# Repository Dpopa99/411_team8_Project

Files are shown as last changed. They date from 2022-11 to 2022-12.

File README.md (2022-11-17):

* Group Member Names: David Popa | Jade Nguyen | Pushpesh Sharma | Shyamal Singh
* Title: ElectroBoom
* Course: ECE411 Fall 2022
* Date: Oct 13, 2022
* Revision: Version 1.0

# Problem Statement and Concept of Operations
Self defense is a necessity in our everyday lives. Whether you go on late night walks in downtown or spend your time in the rural side of town, you have to be prepared to defend yourself in a attack on your person. The stun gun in its mounted state creates a non-lethal electric shock used to stop an intruder from trespassing in an unauthorized area. The device is connected to an entrance door and upon activation of the device, any unauthorized operation of the door will send an electric shock from the device to the door thus immobilizing the assailant. Although they lack some advantages, such as the capacity to render an adversary helpless or a larger range, they are highly regarded for their ease of use and accessibility. The device is mounted, its size and weight make it portable and versatile. The overall product offers a sense of security and vigilance and should be marketed as such. The final marketing team should strongly consider any number of regulations as well as the variance in stand your ground laws within the U.S and internationally. 

# Market Analysis 
As a mounted device, it can be used by a vast number of customers such as small businesses owners, street food vendors, landlords, storage units owners, RV/Van campers, etc. to protect their belongings and themselves.
Over the development of the product, it can be marketed to bigger businesses, corporate offices, banks, armored vehicles, private security firms, as well as in home security companies. 

The competition can be felt through any of the manufacturers selling pre-installed security devices as well as products that offer multipurpose use such as the Ring Doorbell etc. Our product is in a completely different region as it targets a specific audience: the self-made individuals who are vigilant and don't hesitate to do what's necessary to protect what's theirs. 
	
In comparison to other security devices and their features, our device can be priced within the $40-$50 range. There are several key factors that affect this price and as our design and overall ideas develop, the price may be adjusted accordingly. Factors like the mounting apparatus, 3D printed casing, any user interfaces used, and the cost of internal parts such as the transformer, connectors, and the PCB will eventually determine the final price for our product. 

# Product Requirements
* Must be a rugged design for versatile use and placement.
* Must send a non-lethal electric shock.
* Must be marketed as a plug in device. 
* Must not overheat. (Check transformer behavior in various situations)
* Must be operated via a Door actuated sensor. 
* Should have the ability to be deactivated via remote or physical switch. 
* Should have LED indicators to dictate state of device (Armed or Disarmed)
* May have 3D printed enclosure for all components
* May have Display to show state of device (Active, Triggered, Inactive)

# System Architecture (Currently in Design)
Option 1
Option 2

# Design Specification
* Sensor: Door knob movement actuating motion sensor, metal contact to send electric shock
* Processor: ATMega328P microcontroller with Arduino IDE for processing motion sensor activity to send electric shock via transformer. Firmware used will be the Bootloader.  
* Actuator: High voltage transformer taking input voltage and sending converted voltage at variable frequency chosen shock apparatus. 
* Power: 9V wall adapter feeding a high voltage transformer 

# Breadboard Prototype



 As seen from pictures above, the prototype is about finished and all that is needed to have a fully working prototype is the transformer (parts on their way). Image 1 shows the green LED on while the two door sensors are attached, this indicates that the system is armed and ready to go. In the second image, a red LED is shown, meaning that the door has been triggered and the voltage would be discharged out of the two open prongs that would be if the transformer parts were obtained. The video below shows the working prototype.
 
 Current status 11/02/2022: We are awaiting the arrival of our 3.3V to 2000V transformer, upon arrival, we will assemble, test, and commit this transformer to our circuit. Along with this transformer, we will run tests to ensure that the voltage and current combinations will be safe for human contact, however, it is still reccomended that all testing be done by non-human contact, for the safety of our staff, faculty, and students. 

https://user-images.githubusercontent.com/115689153/199646965-d1418cc2-3406-4b21-8939-66e534c145ff.mov

# License
GNU General Public License v2.0
The GNU GPL is the most widely used free software license and has a strong copyleft requirement. When distributing derived works, the source code of the work must be made available under the same license. There are multiple variants of the GNU GPL, each with different requirements.

See Documentation file in this repository for all sources used for this project

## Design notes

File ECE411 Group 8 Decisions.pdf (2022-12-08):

David Popa
Jade Nguyen
Shyamal Singh
Pushpesh Sharma
ECE 411 Group 8

# Stun Gun Decision Making Strategies

Concept 1: Stun Gun Transformer

- Decision Matrix
| | Flyback Transformer | Forward Transformer (LM5015MHE) | Boost Converter (VXO78012)
Output Voltage Range | 5 | 5 | 2 | 1
Current Range | 5 | 4 | 1 | 2
Size | 2 | 3 | 4 | 2
Price | 3 | 5 | 3 | 4
Operating Temperature | 2 | 5 | 3 | 5
Score | | 76 | 38 | 39
- Analytical Hierarchy Process
| | Flyback Transformer | Forward Transformer (LM5015MH E) | Boost Converter (VXO78012)
Output Voltage Range | 0.45 | 0.12 | 0.29 | 0.59
Current Range | 0.40 | 0.26 | 0.43 | 0.32
Size | 0.09 | 0.53 | 0.26 | 0.21
Price | 0.03 | 0.45 | 0.2 | 0.4
Operating Temperature | 0.03 | 0.31 | 0.38 | 0.31
Score | | 0.23 | 0.34 | 0.43

For the transformer, the Decision Matrix vs the AHP values do not match. The calculations for the AHP were based on stars given to some of the categories that could not be quantified and the weights for those specific categories could be the root cause of the differences we see in the tables. For our needs and requirements for the practicum project, we will be choosing the Flyback transformer.

Concept 2: Position Sensor for Stun Activation

- Decision Matrix
Magnetic Door Sensor (Normally Open Closed NC/NO) | Ultrasonic Sensor (HC-SR04) | Motion Sensor (HC-SR501)
Detection | 3 | 5 | 4 | 3
Price | 3 | 2 | 2 | 5
Operating voltage | 4 | 3 | 5 | 3
Trigger range | 2 | 5 | 4 | 3
Delay time | 4 | 5 | 3 | 1
Score | | 63 | 58 | 46
- Analytical Hierarchy Process
Magnetic Door Sensor (NC/NO) | Ultrasonic Sensor (HC-SR04) | Motion Sensor (HC-SR501)
Detection | 0.36 | 0.42 | 0.33 | 0.25
Price | 0.36 | 0.26 | 0.26 | 0.48
Operating voltage | 0.15 | 0.38 | 0.42 | 0.20
Trigger range | 0.1 | 0.40 | 0.32 | 0.28
Delay time | 0.04 | 0.11 | 0.81 | 0.08
Score | | 0.35 | 0.34 | 0.32

The decision matrix and the AHP both point towards the Magnetic Door Sensor. Again some of the categories were given stars to quantify as the actual values were not comparable between the alternatives. The final decision is also based on the overall structure and marketing aspect of our project. Thus we will be going with the Magnetic Door Sensor. Linked Sheets file for all calculations available upon request.

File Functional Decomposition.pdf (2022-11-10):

David Popa
Jade Nguyen
Shyamal Singh
Pushpesh Sharma
ECE 411 Group 8

# Stun Gun Functional Decomposition

Top- Level (Level 0) Block Diagram

Module | Stun Gun Device
Inputs | ● Input Signal from Magnetic Door Sensor ● Power from 9V Wall Adapter ● Toggle Switch to Activate overall System
Outputs | ● Voltage Booster Output: 2kV (Output current: 0.5~1mA; external parallel capacitor can increase the output current) ● LCD and LED displaying system status ● Buzzer Alarm
Functionality | 3.3 V input from Arduino after input signal received from magnetic door sensor as door knob is operated. Voltage boosted through the module up to ~ 2kV to create arc and shock through the hand on door knob. LCD display showing system status as armed or disarmed or trespassed. Green or red LEDs showing system status. Buzzer alarm when trespass detected.

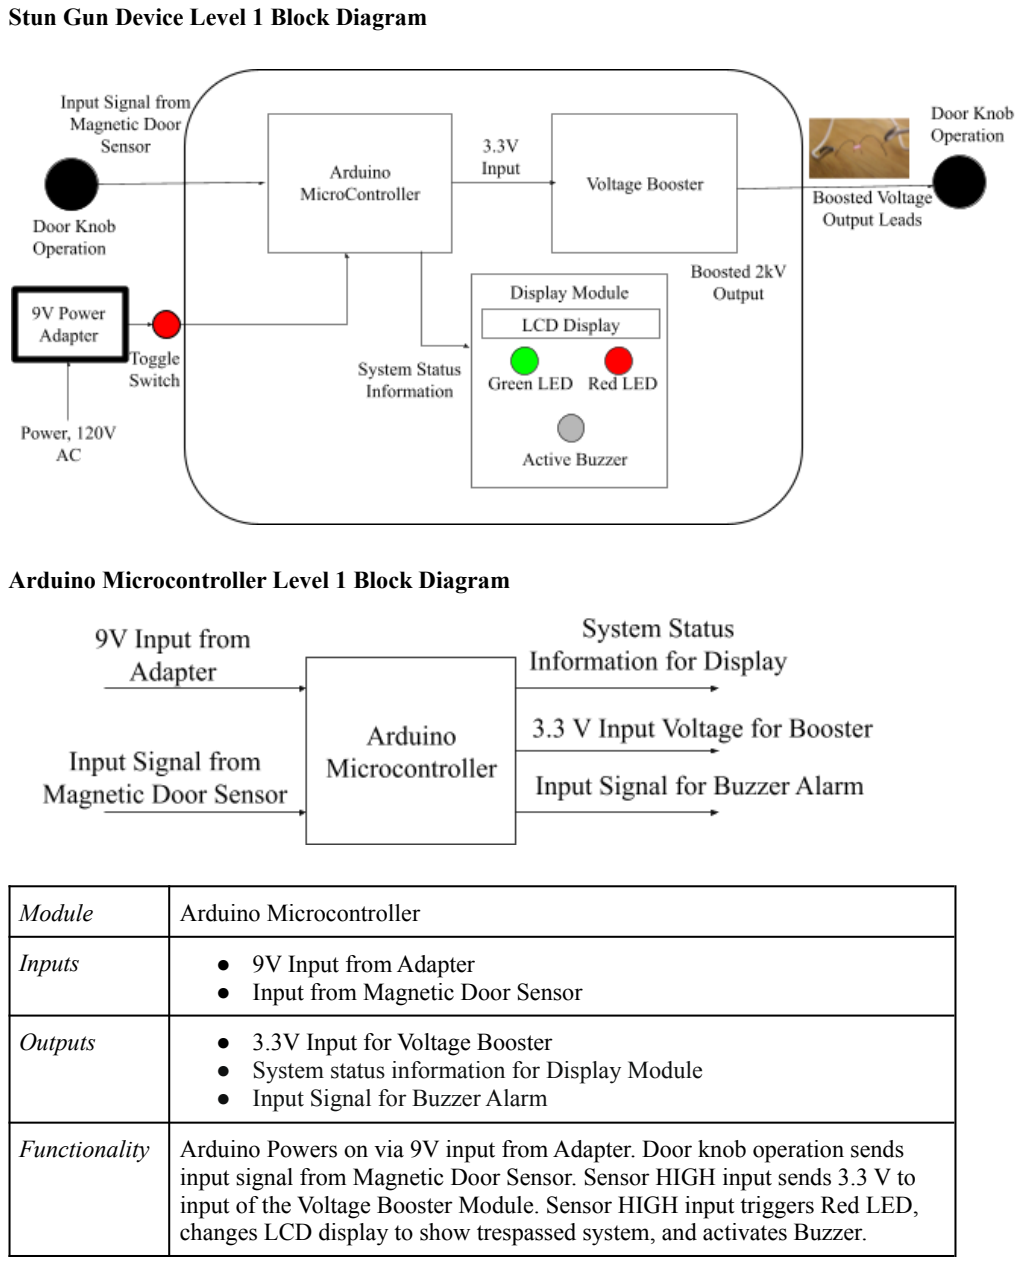
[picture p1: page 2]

Stun Gun Device Level 1 Block Diagram

Arduino Microcontroller Level 1 Block Diagram

Module | Arduino Microcontroller
Inputs | ● 9V Input from Adapter ● Input from Magnetic Door Sensor
Outputs | ● 3.3V Input for Voltage Booster
- System status information for Display Module
- Input Signal for Buzzer Alarm

Functionality Arduino Powers on via 9V input from Adapter. Door knob operation sends input signal from Magnetic Door Sensor. Sensor HIGH input sends 3.3 V to input of the Voltage Booster Module. Sensor HIGH input triggers Red LED, changes LCD display to show trespassed system, and activates Buzzer.

Voltage Booster Level 1 Block Diagram

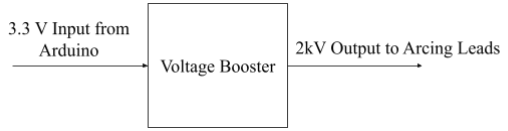
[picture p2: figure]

Module | Voltage Booster
Inputs | ● 3.3V Input from Arduino
Outputs | ● 2000V Output through Arcing Leads connected to door knob.
Functionality | Voltage booster module has active and passive components along with a transformer that boosts the input voltage from 3V-4.2V to 1500V-2000V. The output creates arcing between the two leads and touching the leads sends shock to the user's hand.

Display Module Level 1 Block Diagram

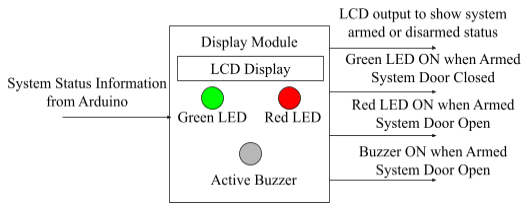
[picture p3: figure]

Module | Display Module
Inputs | ● Input from Arduino
Outputs | ● System status displays on LCD ● LEDs indicates door close/open ● Signal for Buzzer Alarm
Functionality | System status input from the Arduino activates Red LED when sensor input HIGH, which also modifies the LCD display to show the trespassed system and turns on Buzzer.

Power Supply Level 1 Block Diagram

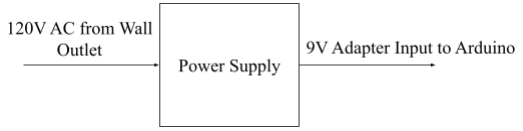
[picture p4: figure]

Module | Power Supply
Inputs | ● 120V AC from wall outlet
Outputs | ● | 9V Adapter Input to Arduino
Functionality | Wall outlet to 9V adapter for arduino. Toggle switch in between to help create
Armed or Disarmed states for the system. No power to the system is disarmed. Once the toggle switch is flipped, system is armed and ready for input signal from Magnetic Door Sensor.

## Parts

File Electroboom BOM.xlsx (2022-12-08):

Bill of Materials
Category | Part Name | Manufacturer | Mfg Part Number | Quantity | Image | Quanity Used | Description | Units Ordered | Cost Each | Cost Total | Distributor | Source
Controller | ELEGOO UNO R3 | ELEGOO | 746591610715 | 1 |  | 4 | ELEGOO UNO R3 Board ATmega328P with USB Cable(Arduino-Compatible) | 4 | $17.99 | $71.96 | Amazon | Elegoo UNO R3 (https://www.amazon.com/ELEGOO-Board-ATmega328P-ATMEGA16U2-Compliant/dp/B01EWOE0UU)
Sensors | Magnetic Door Sensor | Dairzitv | EWWE-87878 | 10 |  | 4 | Surface Mount Wired NC Door Contact Sensor (Pack of 10) | 1 | $1.10 | $10.99 | Amazon | Magnetic Door Sensor (https://a.co/d/hY13WqR)
Actuators | Booster Module | QINIZX | B09BLQQRHL | 2 |  | 4 | Voltage Generator Module Arc Pulse Booster (3V-4.2V boost 2000V) (Pack of 2) | 2 | $5.50 | $21.98 | Amazon | Voltage Booster (https://a.co/d/2gN0GyB)
 | Toggle Switch | AdaFruit | 3218 | 1 |  | 4 | Illuminated Toggle Switch with Cover (Red) Actuation Style: Rocker | 4 | $3.95 | $15.80 | AdaFruit | Toggle Switch (https://www.adafruit.com/product/3218)
Displays | LCD Screen | HiLetgo | 16497 | 2 |  | 4 | LCD Display Module DC 5V 16x2 Character LCM Blue Blacklight (Pack of 2) | 2 | $4.50 | $18.00 | Amazon | LCD Display (https://a.co/d/4aTC4eN)
 | LED indicators | Kingbright | WP154A4SUREQBFZGC | 1 |  | 4 | LED RGB CLEAR T-1 3/4 T/H | 4 | $3.01 | $12.04 | Digikey | RGB LED (https://www.digikey.ca/short/cf37n9db)
Connectors | Header CONN | Molex | 22284028 | 2 |  | 8 | Connector Header Through Hole 2 position 0.100" (2.54mm) | 2 | $0.28 | $0.56 | Digikey | Header (https://www.digikey.com/en/products/detail/molex/0022284028/314032)
 | Arduino Shield Connectors | AdaFruit | 85 | 6 |  | 4 | Shield stacking headers for Arduino (R3 Compatible) | 1 | $0.33 | $1.95 | AdaFruit | Stacking Shield CONN (https://www.adafruit.com/product/85)
 | Arduino LCD Header | Antrader | B07GP3TLH9 | 40 |  | 4 | 2.54mm 16Pin Single Row PBC Female Pin Header Socket Connector Strip | 1 | $0.16 | $6.49 | Amazon | 16 Pin Header (https://a.co/d/b6fevxA)
Passive Compnents | 300 Ohm Resistor | YAGEO | RC0805JR-07330RL | 1 |  | 8 | RES 330 OHM 5% 1/8W 0805 | 8 | $0.10 | $0.80 | Digikey | 300 Ohm Resistor (https://www.digikey.com/short/ntbppq7n)
 | 10k Ohm Resistor | YAGEO | RC0805FR-0710KL | 1 |  | 4 | RES 10K OHM 1% 1/8W 0805 | 4 | $0.10 | $0.40 | Digikey | 10k Ohm Resistor (https://www.digikey.com/short/373h2zrv)
 | Potentiometer | Bourns | 3362P-1-103LF | 1 |  | 4 | TRIMMER 10K OHM 0.5W PC PIN TOP | 4 | $1.03 | $4.12 | Digikey | Trimmer (https://www.digikey.com/en/products/detail/bourns-inc./3362P-1-103LF/1088412)
 | SMD Diode | MDD | 1N4148W | 1 |  | 4 | Diode Standard 100 V 150mA Surface Mount SOD-123 | 4 | $0.05 | $0.18 | Digikey | Diode (https://www.digikey.com/en/products/detail/nextgen-components,-inc./1N4148W%2520T4/14825027)
 | Switch | E-Switch | EG1218 | 1 |  | 4 | Slide Switch SPDT Through Hole | 4 | $0.76 | $3.04 | Digikey | Onboard Switch (https://www.digikey.com/en/products/detail/e-switch/EG1218/101726)
 | IR Sensor and Remote | DFRobot | 2152315 | 1 |  | 4 | Infrared Remote & IR Receiver Combo Arduino Compatible | 4 | $7.49 | $29.96 | Jameco | IR sensor and Remote (https://www.jameco.com/z/DFR0107-DFRobot-Infrared-Remote-IR-Receiver-Combo-Arduino-Compatible_2152315.html)
Power | 9V Batteries | Duracell | MN1604B4 | 4 |  | 4 | Duracell Coppertop 9V Battery (Pack of 4) | 1 | $3.05 | $12.19 | Amazon | 9V Batteries (https://a.co/d/fda0Lso)
 | 9V Battery Connector | RFAdapter | B0882VV74L | 6 |  | 4 | 9v Battery Clip with 5.5mm/2.1mm Male DC Plug | 1 | $1.00 | $5.99 | Amazon | 9V Battery Connector (https://a.co/d/hpMY8ct)
 | Power Adapter | Corporate Computer | LJH -186 | 1 |  | 4 | 9VDC 1A Arduino Compatible Power Supply Adapter 110V AC 5.5 x 2.1mm Tip | 4 | $7.49 | $7.49 | Amazon | 9V Battery Adapter (https://a.co/d/gGLW0Xa)
EDA | PCB Fabrication | OshPark | n/a | 4 |  | 4 | Layout to house and control LCD display, LED indicators, and Voltage Booster Module | 1 | $7.14 | $28.55 | OshPark | OshPark (https://oshpark.com/)
Component Housing | 3D Enclosure v1 | EPL | n/a | 1 |  | 4 | 3D Enclosure for Component Housing | 4 | $15.00 | $60.00 | EPL | 3DPrinting (http://psu-epl.github.io/doc/equip/printer/3D-Printers.html)
 | 3D Enclosure v2 | EPL | n/a | 1 |  | 4 | 3D Enclosure for Component Housing | 4 | $20.00 | $80.00 | EPL | 3DPrinting (http://psu-epl.github.io/doc/equip/printer/3D-Printers.html)
 |  |  |  |  |  |  | Total Cost for all Components: |  |  | $392.49
Revisions | Date |  |  |  |  |  | Total Cost Per Device: |  | $96.90
v1: Added Headers for PCB | 2022-10-12 |  |  |  |  |  | Total Cost for all 4 Devices: |  | $387.58
v2: Added 9V Battery Connector | 2022-10-31
v3: Added IR sensor and Remote | 2022-11-15
v4: Added Toggle Switch | 2022-11-17
v5: Added PCB | 2022-11-21
v6: Added 3D enclosure v1 | 2022-12-01
v7: Added 3D enclousre v2 | 2022-12-04

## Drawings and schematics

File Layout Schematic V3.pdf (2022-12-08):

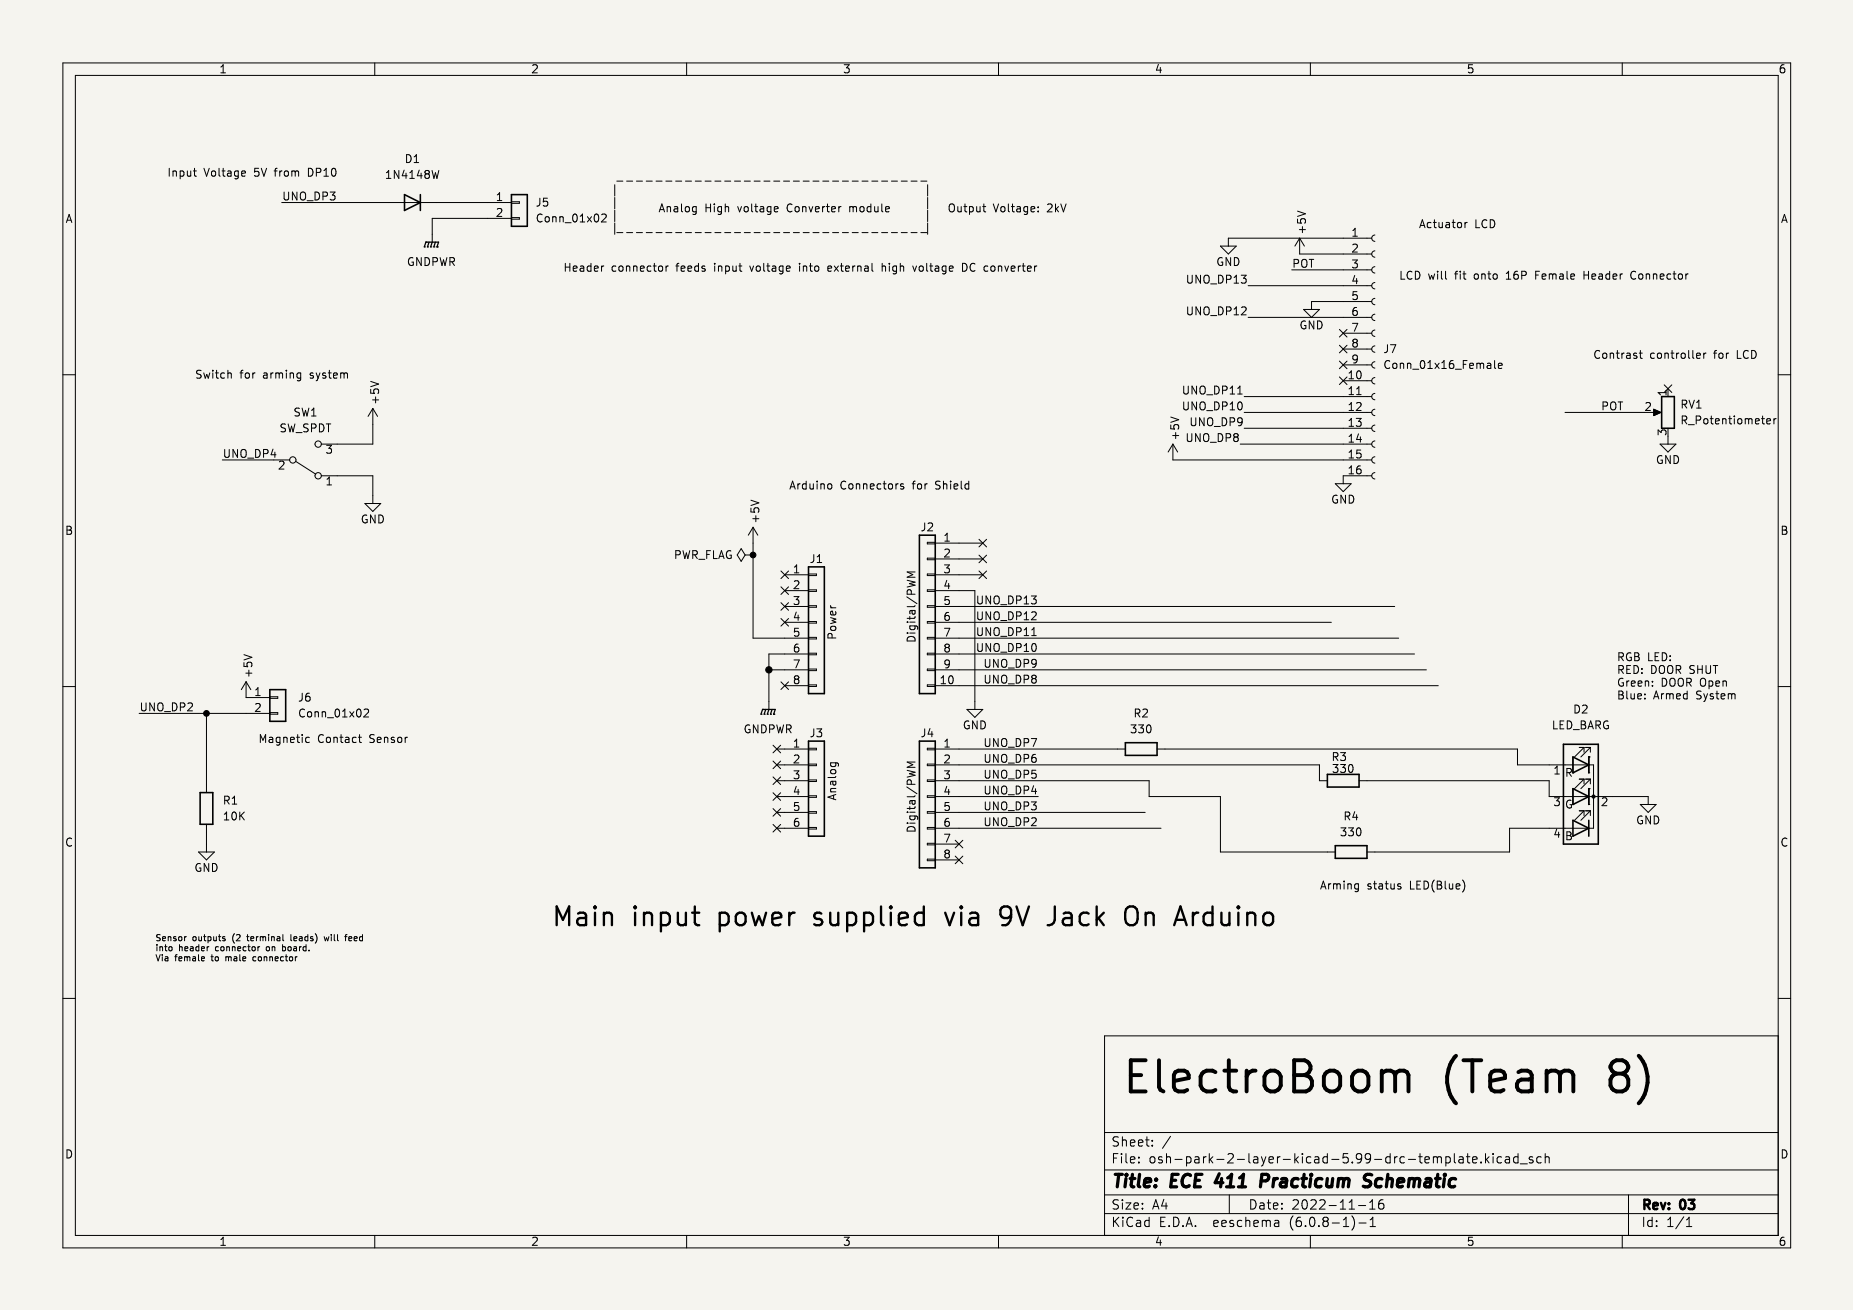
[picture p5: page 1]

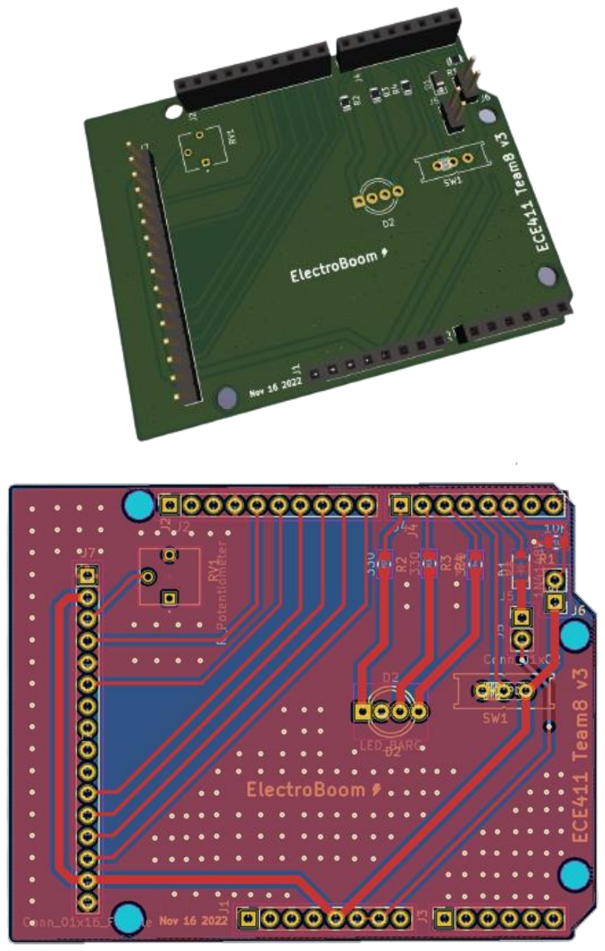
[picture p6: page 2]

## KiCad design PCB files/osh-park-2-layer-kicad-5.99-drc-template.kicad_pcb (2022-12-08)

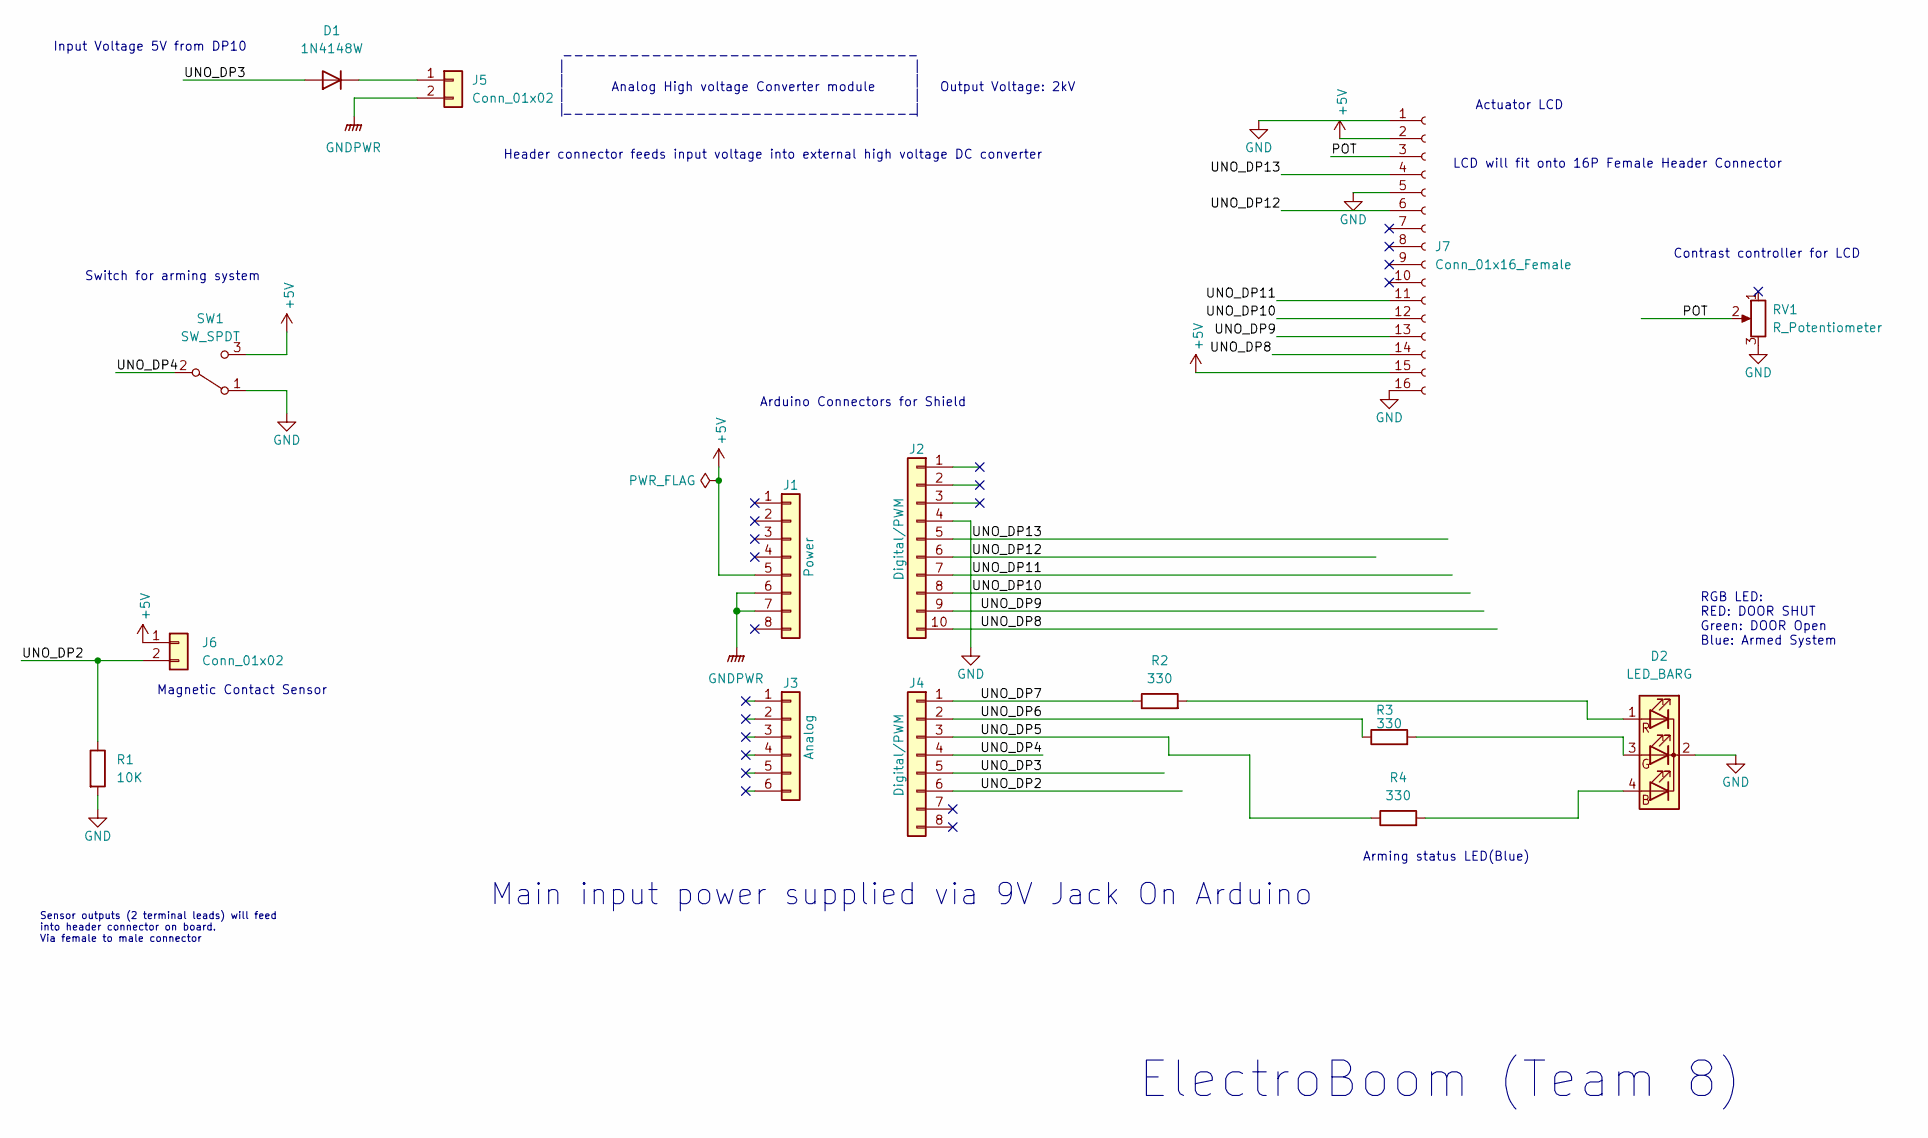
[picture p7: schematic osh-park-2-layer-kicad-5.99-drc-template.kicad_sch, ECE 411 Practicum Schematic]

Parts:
D1: 1N4148W; D_SOD-123
D2: LED_BARG; LED_D5.0mm-4_RGB_Wide_Pins
J1: Power; PinSocket_1x08_P2.54mm_Vertical
J2: Digital/PWM; PinSocket_1x10_P2.54mm_Vertical
J3: Analog; PinSocket_1x06_P2.54mm_Vertical
J4: Digital/PWM; PinSocket_1x08_P2.54mm_Vertical
J5, J6: Conn_01x02; PinHeader_1x02_P2.54mm_Vertical
J7: Conn_01x16_Female; PinHeader_1x16_P2.54mm_Vertical
R1: 10K; R_0805_2012Metric
R2, R3, R4: 330; R_0805_2012Metric
RV1: R_Potentiometer; TRIM_3362P-1-505LF
SW1: SW_SPDT; EG1218

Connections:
+5V: J1.5, J6.1, J7.2, J7.15, SW1.3 (C)
/POT: J7.3, RV1.2
/UNO_DP2: J4.6, J6.2, R1.1
/UNO_DP3: D1.2 (A), J4.5
/UNO_DP4: J4.4, SW1.2 (B)
/UNO_DP5: J4.3, R4.1
/UNO_DP6: J4.2, R3.1
/UNO_DP7: J4.1, R2.1
/UNO_DP8: J2.10, J7.14
/UNO_DP9: J2.9, J7.13
/UNO_DP10: J2.8, J7.12
/UNO_DP11: J2.7, J7.11
/UNO_DP12: J2.6, J7.6
/UNO_DP13: J2.5, J7.4
GND: D2.2 (A), J2.4, J7.1, J7.5, J7.16, R1.2, RV1.3, SW1.1 (A)
GNDPWR: J1.6, J1.7, J5.2
unnamed: D1.1 (K), J5.1
unnamed: D2.1 (BK), R2.2
unnamed: D2.3 (RK), R3.2
unnamed: D2.4 (GK), R4.2

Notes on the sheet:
Main input power supplied via 9V Jack On Arduino
RGB LED: RED: DOOR SHUT Green: DOOR Open Blue: Armed System
Input Voltage 5V from DP10
Arduino Connectors for Shield
LCD will fit onto 16P Female Header Connector
| | | |
Arming status LED(Blue)
Output Voltage: 2kV
Header connector feeds input voltage into external high voltage DC converter
Actuator LCD
Analog High voltage Converter module
Switch for arming system
--------------------------------
Contrast controller for LCD
Sensor outputs (2 terminal leads) will feed into header connector on board. Via female to male connector
Magnetic Contact Sensor
ElectroBoom (Team 8)

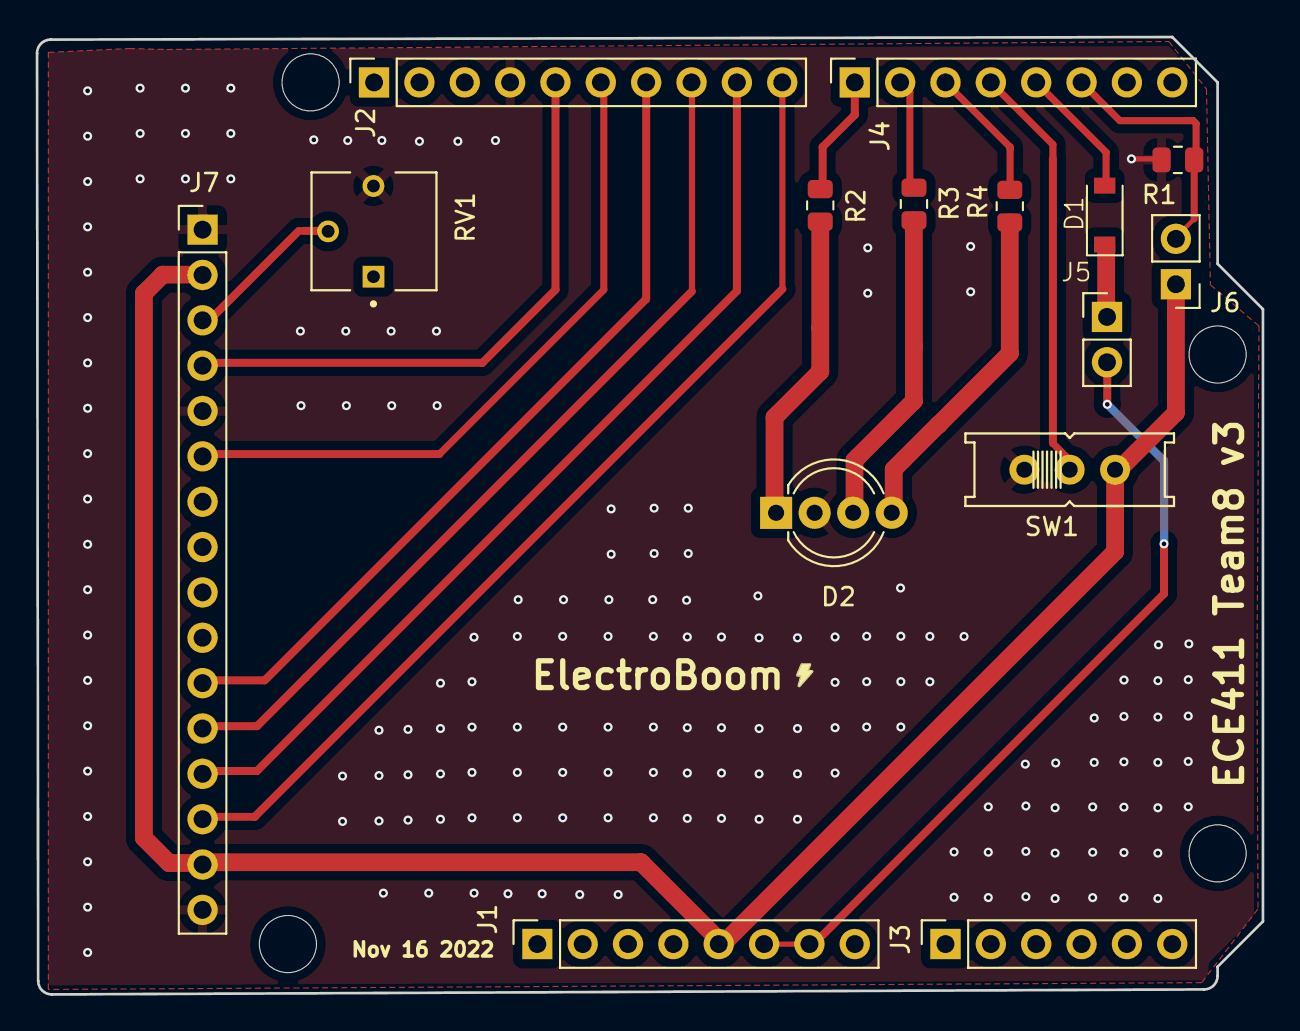
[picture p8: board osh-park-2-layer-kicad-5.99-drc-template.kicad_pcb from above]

Board: 2 copper layers, 68.7 x 53.6 mm, 19 parts (0 on the bottom side), 20 nets.

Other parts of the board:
MH1, MH2, MH3, MH4: MountingHole_3.2mm

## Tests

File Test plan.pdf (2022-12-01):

Test Author: David Popa, Pushpesh Sharma
Test Case Name: | Electroboom Code Test #1 | Test ID #: | Electroboom-CT-01
Description: | Checks that our project works as needed. Switching states and ultimately sending voltage through to the leads and arcing when touched. | Type: | ✔ white box □ black box □ ________

Tester Information
| Name of Tester: | David Popa , Pushpesh Sharma Jade Nguyen Shyamal Singh | Date: | 11/26
| SW Version: | Elecode Boom | Time:
| Setup: | Security device should be fully wired onto the Arduino
S T E P | Action | Expected Result | P A S S | F A I L | N / A | Comments
1 | Power on Arduino | LCD displays state of door, wait for IR response | ✔
2 | Press 0 on remote | LCD displays state of door and displays that the system is unarmed, GreenLED on | ✔
3 | Open the door | LCD displays door open and displays that the system is unarmed, GreenLED on | ✔
4 | Close the door | LCD displays door closed and displays that the system is unarmed, GreenLED on | ✔
5 | Press 1 on remote | LCD Displays door closed and displays that the system is armed, Red LED on | ✔
6 | Open the door | LCD displays door open, and displays that the system is sending voltage through, Blue LED on, voltage flows from arduino to the transformer, through the booster module and to the leads | ✔
7 | Touch output leads together | Voltage arcs and LCD displays a delay timer | ✔
8
| Overall test result: | | ✔

Test Author: David Popa, Jade Nguyen

Test Case Name: | Electroboom Boost Module Test #2 | Test ID #: | Electroboom-BMT-01
Description: | Check to see if purchased boost module works with our circuit and output voltage and current levels are safe for human touch | Type: | □ white box ✔ black box □ ________

Tester Information
| Name of Tester: | David Popa , Pushpesh Sharma Jade Nguyen Shyamal Singh | Date: | 10/25
| HW Version: | Boost module 1.0 | Time:
| Setup: | Boost module should be connected to our 9V power supply (9V battery)
S T E P | Action | Expected Result | P A S S | F A I L | N / A | Comments
1 | Connect 9V battery to Boost module input | Boost module should turn on | ✔
2 | Test output voltage | Output Voltage should be at 2k | ✔ | | | Boost module is rated for 3V to 2kV
3 | Test output current | Output Current should be under 10mA | ✔ | | | Break the circuit before the output and put a DMM in series, a human can tolerate 2kV at 10mA, output reading was at 4mA
4 | Touch leads together | Voltage should arc | ✔
5 | Touch leads with hand | Ow! | ✔✔ | | | Should hurt, not too bad, the anticipation and the sudden zap causes more pain than the shock itself

6

Test Author: Pushpesh sharma, Shaymal Signh
Test Case Name: | Electroboom Code Test #3 | Test ID #: | Electroboom-CT-02
Description: | We need to make sure that the IR sensor works before implimenting it onto our code. In order to do this, we must run a fundamental test. | Type: | □ white box ✔black box □ ________

Tester Information
| Name of Tester: | David Popa , Pushpesh Sharma Jade Nguyen Shyamal Singh | Date: | 11/30
| SW Version: | Elecode Boom 2.7 | Time:
| Setup: | Hook up Ir Sensor with the Arduino to turn on the light
S T E P | Action | Expected Result | P A S S | F A I L | N / A | Comments
1 | Hook up Arduino to computer | Arduino is found by the computer | ✔
2 | Install IR Sensor | N/a | | | ✔
3 | Go through Serial print to find hex values of remote | Find the hex value for 1 and 0 and write them down | ✔
4 | Code to have 0 go green (unarmed) | Whenever 0 is pressed, have the RGB LED go green (system is unarmed) | ✔
5 | Code to have 1 go red/blue (arm) | Whenever 1 is pressed, have the RGB LED switch to red when the door close/ blue when the door opens to confirm the switching of states (system is armed) | ✔

6
7
8
9
| Overall test result: | | ✔

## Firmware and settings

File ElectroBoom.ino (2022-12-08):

#include <IRremote.h>
#include <IRremoteInt.h>

#include <LiquidCrystal.h>

const int rs = 13, en = 12, d4 = 11, d5 = 10, d6 = 9, d7 = 8;         // Pin Assignments for LCD
LiquidCrystal lcd(rs, en, d4, d5, d6, d7);

int Sensor = 2;                                                       // Magnetic Door Sensor Input
int Transformer = 3;                                                  // Output to Voltage Booster Module
int Remote = 4;                                                       // Remote Input to Arm or Disarm Device
int Buzzer = A1;                                                      // Output to Buzzer

IRrecv irrecv(Remote);                                                // Take input from IR Receiver
decode_results results;                                               // Convert Received Value to HEX

int LEDBlue = 5;                                                      // Armed System LED (Door Open)
int LEDGreen = 6;                                                     // Unarmed System Status (Door Open or Closed)
int LEDRed = 7;                                                       // Armed System Status (Door Closed)

boolean SystemArmed = false;                                          // Flag for System Status
boolean Button = false;                                               // Flag for IR Receiver Status

void setup() 
{
  lcd.begin(16, 2);
  //Inputs
  pinMode(Sensor, INPUT);
  pinMode(Remote, INPUT);

  //Outputs
  pinMode(Transformer, OUTPUT);
  pinMode(LEDBlue, OUTPUT);
  pinMode(LEDGreen, OUTPUT);
  pinMode(LEDRed, OUTPUT);
  pinMode(Buzzer, OUTPUT);
  digitalWrite(Transformer, LOW);
  digitalWrite(LEDBlue, LOW);
  digitalWrite(LEDGreen, LOW);
  digitalWrite(LEDRed, LOW);
  irrecv.enableIRIn();                                                // Start the Receiver
  Serial.begin(9600);                                                 // Start the Serial Monitor
}

void loop()
{
  if ((digitalRead(Sensor) == HIGH) && (SystemArmed == true))         //Status Check for Door being Closed and Armed
  {
    Serial.println("System Armed");
    Serial.println("Door Closed");
    analogWrite(LEDRed, 255);
    analogWrite(LEDGreen, 0);
    analogWrite(LEDBlue, 0);
    digitalWrite (Transformer, LOW);
    lcd.clear();
    lcd.setCursor(2, 0);
    lcd.write("Door Closed!");
    lcd.setCursor(2, 1);
    lcd.write("System Armed");
    Button = false;

    while ((digitalRead(Sensor) == HIGH) && (Button == false))
    {
      if (irrecv.decode(&results))
      {
        if (results.value == 0XFF6897)
        { 
          SystemArmed = false;
          Button = true;
        }
          irrecv.resume();
      }
    }
  }
  if ((digitalRead(Sensor) == LOW) && (SystemArmed == true))        //Status Check for Door being Open and Armed
  {
    lcd.clear();
    lcd.setCursor(4, 0);
    lcd.write("Shocking");
    lcd.setCursor(3, 1);
    lcd.write("Isn't It??");
    Button = false;

    while ((digitalRead(Sensor) == LOW) && (Button == false))       // Shocking Stage. Door is Opened and System is Armed. Device Waits for Door Sensor Change or Remote Input
    {                                                                 
      if (irrecv.decode(&results)) 
      {
        if (results.value == 0XFF6897) 
        {                            
          SystemArmed = false;
          Button = true;
        }
          irrecv.resume();
      }
      if ((digitalRead(Sensor) == LOW) && (Button == false))
      {
        Serial.println("Shock Stage");
        Serial.println("System Waiting for Sensor or Remote Input");
        analogWrite(LEDRed, 0);
        analogWrite(LEDGreen, 0);
        analogWrite(LEDBlue, 255);
        digitalWrite(Transformer, HIGH);
        digitalWrite(Buzzer, HIGH);
        delay(2000);
        digitalWrite(Transformer, LOW);
        digitalWrite(Buzzer, LOW);
        delay(1000);
      }
    }
  }
  if ((digitalRead(Sensor) == LOW) && (SystemArmed == false))       //Status Check for Door being Open and Unarmed
  {
    Serial.println("System Unarmed");
    Serial.println("Door Open");
    analogWrite(LEDRed, 0);
    analogWrite(LEDGreen, 255);
    analogWrite(LEDBlue, 0);
    digitalWrite (Transformer, LOW);
    lcd.clear();
    lcd.setCursor(3, 0);
    lcd.write("Door Open!");
    lcd.setCursor(1, 1);
    lcd.write("System Unarmed");
    Button = false;

    while ((digitalRead(Sensor) == LOW) && (Button == false)) 
    {
      if (irrecv.decode(&results)) 
      {
        if (results.value == 0xFF30CF) 
        {  
          SystemArmed = true;
          Button = true;
        }
          irrecv.resume();
      }
    }
  }
  if ((digitalRead(Sensor) == HIGH) && (SystemArmed == false))      //Status Check for Door being Closed and Unarmed
  {
    Serial.println("System Unarmed");
    Serial.println("Door Closed");
    analogWrite(LEDRed, 0);
    analogWrite(LEDGreen, 255);
    analogWrite(LEDBlue, 0);
    digitalWrite (Transformer, LOW);
    lcd.clear();
    lcd.setCursor(2, 0);
    lcd.write("Door Closed!");
    lcd.setCursor(1, 1);
    lcd.write("System Unarmed");
    Button = false;
    while ((digitalRead(Sensor) == HIGH) && (Button == false)) 
    {
      if (irrecv.decode(&results)) 
      {
        if (results.value == 0xFF30CF) 
        {  
          SystemArmed = true;
          Button = true;
        }
          irrecv.resume();
      }
    }
  }
}

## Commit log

2022-10-27 Add files via upload
    Preliminary Schematic Design
    [STUN_PRELIM.kicad_sch]
2022-11-15 Create BOM
2022-11-17 Add files via upload
    Final version (V3) for layout/schematic
    [osh-park-2-layer-kicad-5.99-drc-template-B_Cu.gbr, osh-park-2-layer-kicad-5.99-drc-template-B_Mask.gbr, osh-park-2-layer-kicad-5.99-drc-template-B_Paste.gbr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]
